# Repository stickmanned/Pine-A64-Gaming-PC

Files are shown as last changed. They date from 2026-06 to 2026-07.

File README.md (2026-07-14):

# Pine A64 Gaming PC

<div align="center">
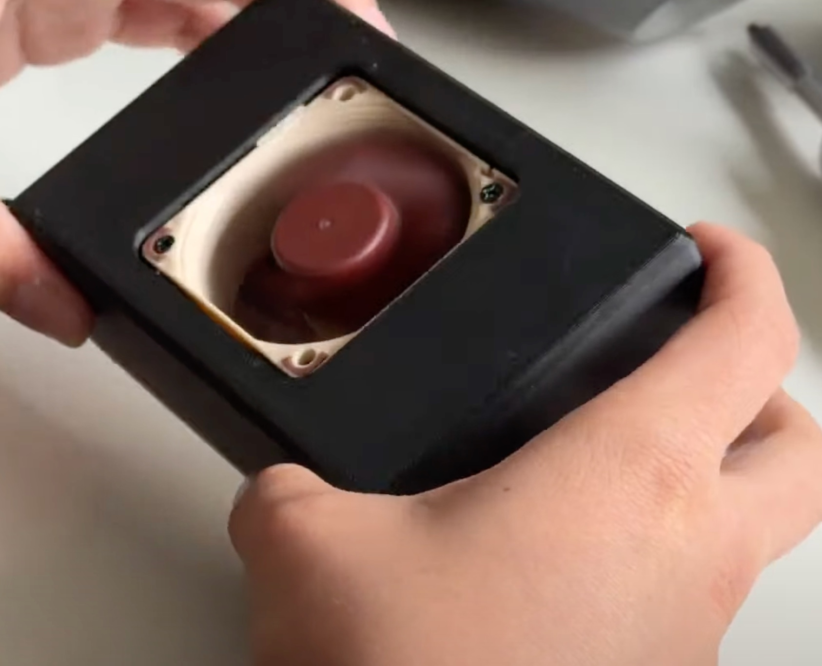
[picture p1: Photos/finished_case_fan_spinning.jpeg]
The final Pine A64 PC build
  
</div>

## Prologue

I got the PINE A64 single-board computer after getting second place at the Equinox hackathon in Vancouver. It originally came in an quite fancy display case made with metal bolts and acrylic. For months, I kept it in its display case on my bookshelf and every time I walked past it, it reminded me that I had a usable computer which I had no plan for.

At the same time, I was using Moonlight to stream games from my main PC because I have a MacBook and I am unable to play some of my favorite games on it; additionally, my room gets too hot during the summer, which with the addition of my PC makes it even hotter. My first idea was to use another normal computer as the receiver, as I have an old Windows laptop lying around, but using a whole computer to stream from another computer felt wasteful and unoriginal. Plus, the laptop's ports were all broken due to a faulty BIOS chip, so I could not connect any peripherals to it. The Pine A64 seemed like a perfect middle ground to my problem: Being small and portable, generating almost no heat due to having a low-powered CPU, and having gigabit ethernet with the addition of a full size HDMI port which I can connect a larger display to.

Back in 2025, around summer, I just set up Moonlight game streaming, which blew me away on how smooth and simple it was. The problem was that I wanted a computer in each of my rooms so I can all connect them to my host PC; therefore, performance would not matter with the added benefits of less heat generation. When I heard about Hack Club Horizons, after winning the PINE A64, I was was finally ready to build it, and I wanted to go to the hackathon, so I submitted it as a Horizons project too with all my hours logged. I came up with the enclosure, created a cooling solution with a spare Noctua fan lying around, power button, software setup, and the rest of the project myself.

## The finished computer

The name "Gaming PC" is a little generous because the Pine A64 is receiving the rendered game from my main PC, not running games locally. I am running DietPi on the microSD card, and along with Moonlight installed, I streamed games over Ethernet. That essentially is all there is on the software side. Physically, I stuck copper heatsinks onto the board, placed a Noctua NF-A6x25 fan above them with the correct voltage control module to output 12V, and then I designed and made a printed case fit around all of it and attached a power button to turn it on and off.

In my final test of the computer, games streamed in 720p with around 20-30 FPS. Fast games such as shooters are not great on it. Slower story games such as driving games are somewhat enjoyable, which surprised me because this is old and slow hardware, and I honestly never expected it to stream games in the first place.

I tried getting hardware video decoding to work and changed a lot of settings, but I kept running into video problems. The finished setup is mainly decoding on the CPU. Its Gigabit Ethernet connection is fine and is definitely not the bottleneck; the video hardware is where it struggles as the CPU is really slow even back in 2016.

Pressing the power button/plugging in the 5V power supply starts the board, and after the first boot checks it goes into Moonlight by itself. I timed about 10 seconds from the press to Moonlight. My button is just a mechanical keyboard switch wired to the Pine A64 power header. It tells the operating system to shut down, rather than yanking the power every time I want the PC to shut down.

The Pine A64 only gets 5V; therefore, I used an MT3608 boost converter to make 12V for the cooling fan, and that 12V output does not draw too much power from the board. The physical power switch was also in the correct orientation during testing. It was not responsible for the crashes that I was experiencing.

[Here is the video of Roblox and BeamNG.drive running on it,](https://photos.app.goo.gl/yZgWkz5E3pNsgPrR7)

<div align="center">
  The fan and Pine A64 before I closed the case
</div>

<div align="center">
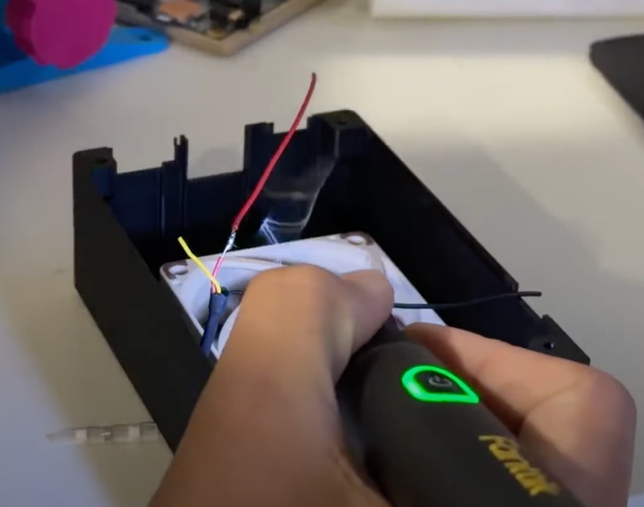
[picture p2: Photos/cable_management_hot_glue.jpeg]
The wiring after I fixed it in place
  
</div>

## Steps to Reproduce

If you want to build this Pine A64 Gaming PC yourself (which I don't recommend since you can get way faster hardware in 2026+, such as a Raspberry Pi), you can follow these steps to manufacture the parts, assemble the hardware, flash the software, and test the final build. 

### 1. Prepare
Before assembling, you would need the following components:

1. **Buy these Components:** 
   Source a Pine A64 board (used ones are like free at this point) a Noctua NF-A6x25 FLX 12V DC fan (get the 5V version if possible), an MT3608 boost converter (if voltages are incompatible), a Cherry MX style mechanical switch (does NOT matter which one you get), copper heatsinks (raspberry pi ones work great), a reliable microSD card (the first microSD failed on me since I got it from shady chinese seller), and wiring hardware.

   <div align="center">
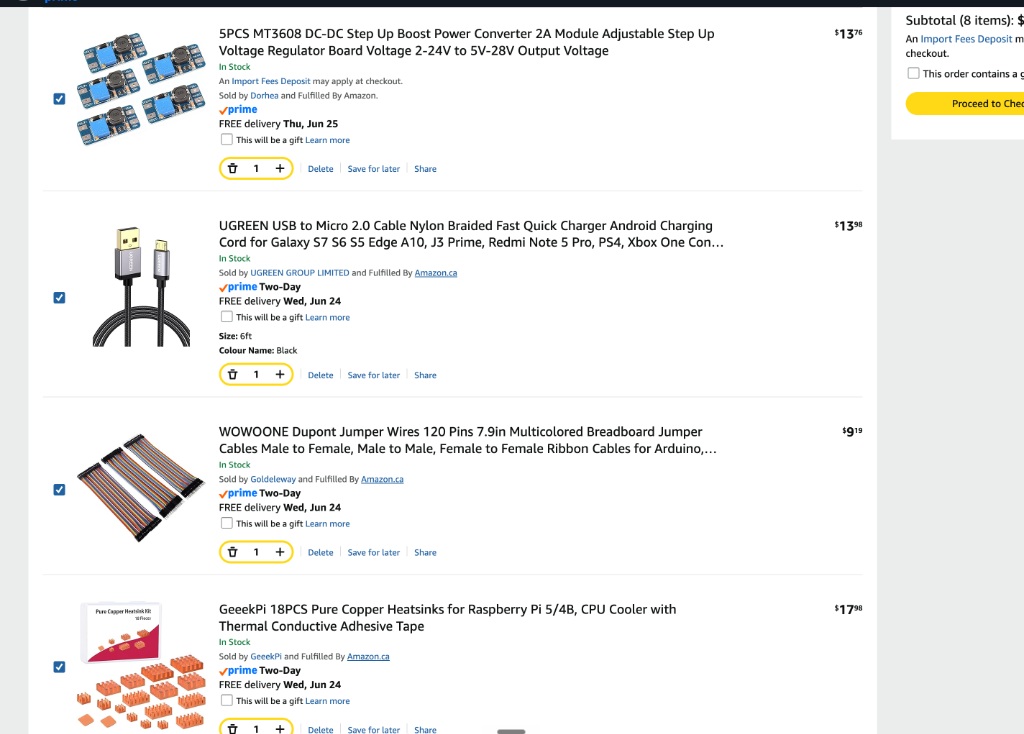
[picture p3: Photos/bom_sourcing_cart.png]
BOM sourcing
     
   </div>

   **You will also need the following**

   - Soldering Iron
   - Multimeter
   - Good quality power brick + microUSB cable
   - 3D printer to print the case and power button
   - Appropriate hardware, such as screws, solder, hot glue gun, etc.
   - Another computer to flash the OS and SSH into the board
   - Monitor
   - Ethernet cable to connect to the network
   - Micro SD card

2. **3D Print the Enclosure:** Use the provided files in the `CAD/` folder.
   * **Top Shell:** Print with 0.20 mm layers and 10% gyroid infill (supports required under the fan cutout). If you have a tool changer 3D printer, I recommend using dedicated support material for easy removal.
   * **Bottom Shell:** Print with 0.16 mm layers and 15% gyroid infill (no supports required).
   
   <div align="center">
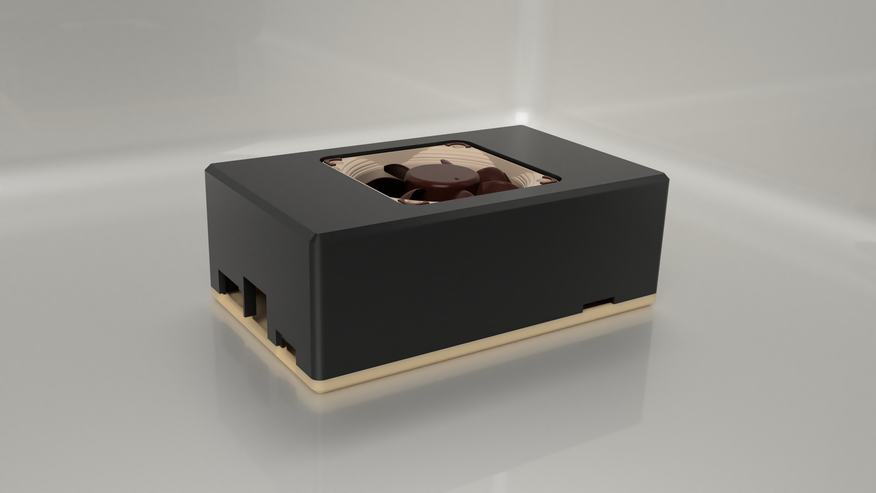
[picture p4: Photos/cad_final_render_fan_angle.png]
CAD render fan angle
     
   </div>

3. **Print the Keycap:** Print the `CAD/power-button-keycap-v3.stl` file for the custom power button keycap, which will fit the case (normal sized keycaps won't fit the cutout).

### 2. Assemble

**Make sure power is disconnected from the Pine A64 before you start assembling**

1. **Install Heatsinks:** Apply the copper heatsinks to the CPU, RAM, and SD card slot before putting anything in the case.
2. **Mount the Fan:** Slide the Noctua fan into the top enclosure and secure it to the internal pillars with M3 screws. Expect to use more force than expected to fit it in. Super gluing the fan onto the pillars is highly recommended since 3D printed inserts might get loose over time.
3. **Wire the Power Switch:** Solder the Cherry MX switch leads to the Pine A64 EXP header (Pin 5 and Pin 6). Snap the switch into the side panel cutout, and after put on the power button keycap.
   
   <div align="center">
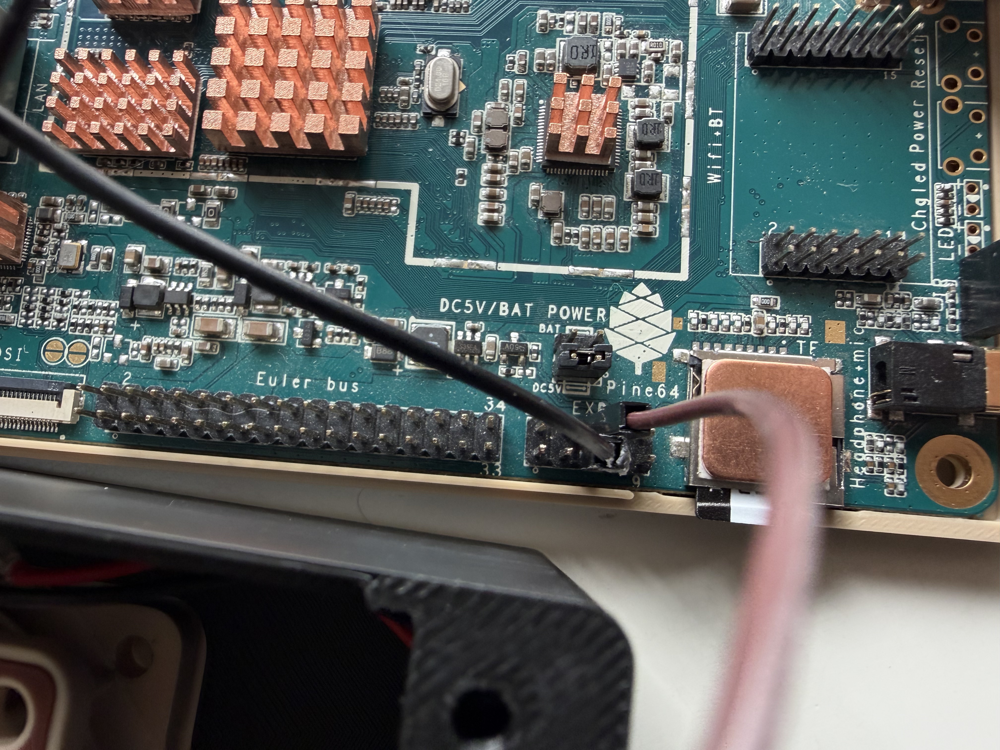
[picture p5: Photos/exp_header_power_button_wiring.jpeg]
EXP header wiring
     
   </div>
   
4. **Wire the Cooling System:** Connect the MT3608 boost converter input to the Pi-2 Bus header 5V (Pin 2) and GND (Pin 6). **IMPORTANT:** Tune the MT3608 output to exactly 12.0V using a multimeter *before* connecting the fan. You can use a flathead screwdriver to rotate the knob until you get an output of 12V. After, connect the fan's red wire to `OUT+` and black to `OUT-`. do not connect the yellow wire. 
   
   <div align="center">
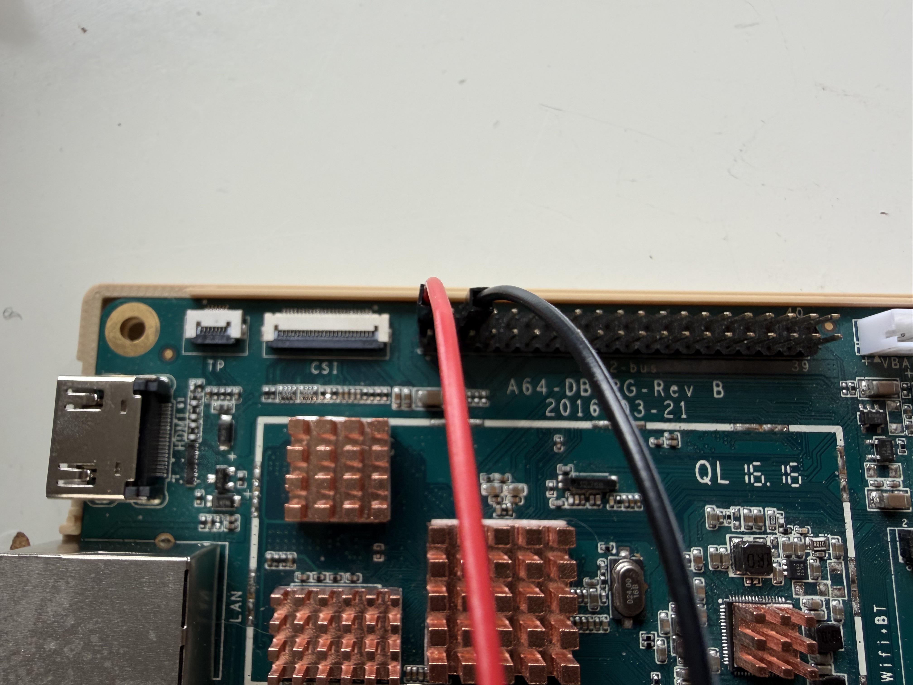
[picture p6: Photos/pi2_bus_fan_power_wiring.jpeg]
Pi-2 Bus fan power wiring
     
   </div>
   
5. **Final Assembly:** Hot glue the wires and MT3608 to the inside of the printed shell, tidy up the cables, and place the board in the bottom shell and screw the top and bottom pieces together using four M3 screws.

### 3. Flash (software configuration)
Here is the tricky part in my opinion:

1. **Flash OS:** Flash DietPi onto a high-quality microSD card. Low-end ones are unreliable and often are the cause of booting issues (speaking from experience). After, insert the microSD card into the Pine A64 and follow the install instructions.
2. **Configure Display:** Edit `/boot/dietpiEnv.txt` to inject a strict resolution limit (e.g., `video=HDMI-A-1:1920x1080@60`). This frees up memory for the hardware video decoder, so you get more frames in Moonlight.
3. **Remove Desktop:** Uninstall the graphical desktop environment completely so the board boots directly to a bare terminal. This saves memory and prevents the X11 overhead.
4. **Setup Moonlight:** Install Moonlight and configure it to run in embedded mode using the KMSDRM video driver.
5. **Configure Autostart:** Add Moonlight to the root user's `.bashrc` profile with a short `sleep 3` delay to avoid race conditions. Write a udev rule to grant open read/write access to the GPU nodes (`/dev/dri/card0` and `/dev/dri/renderD128`).

### 4. Testing

1. **Pre-Power Safety Check:** Ensure 12V from the boost converter only goes to the fan, and never touches the Pine A64 board. 
2. **Power On:** Supply 5V power to the board via micro USB. The board should power on without pressing the power button.
3. **Verify Cooling:** The Noctua fan should spin up and direct air downwards onto the copper heatsinks.
4. **Verify Boot:** Connect the board to an Ethernet network and an HDMI display. It should boot directly into Moonlight in about 10 seconds. A terminal like startup is normal.
5. **Stream:** Pair Moonlight with your host PC and start a game to verify hardware decoding is functioning properly. You should expect low frame rates since the Pine A64 is weak & old, but it should be playable.
   
   <div align="center">
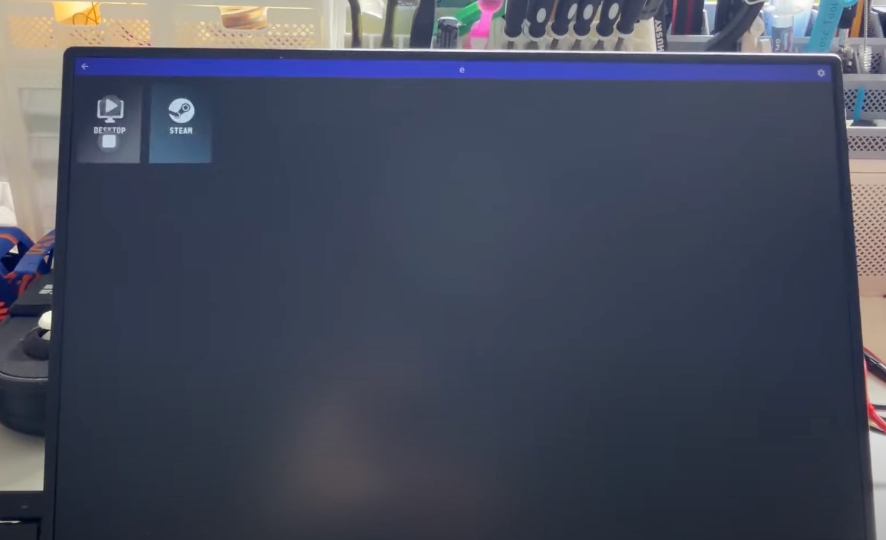
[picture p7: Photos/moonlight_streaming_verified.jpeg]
Moonlight streaming
     
   </div>
   
6. **Test Power Button:** Long press the power button, and you should see the Pine A64 shut down within a few seconds. Short press and it will turn on again.

## Build files and proof
Here are all the relevant build files if you are checking out this project or if you want to replicate it for yourself.

- [24-hour devlog](./Devlog.md) - everything that happened in the 24 hours the project took
- [CAD folder](./CAD) - all the CAD files, such as Fusion and 3D printing files\*
- [wiring PDF](./Hardware/wiring-schematic.pdf) - wiring diagram
- [DietPi and Moonlight configuration](./firmware-config) - OS and software configuration
- [parts and prices](./Pine%20A64%20PC%20Bill%20of%20Materials.csv) - parts and prices
- [recorded build sessions timelapses](https://drive.google.com/drive/folders/1OZEimO6eNiohD2dQr07wJ2Tfkh4ZQb1m?usp=sharing) - recorded build sessions timelapses
- [project spreadsheet](https://docs.google.com/spreadsheets/d/1We2MmTOR3fEgsacE6zURNgYWdwFos29sACSzlIPlyxY/edit?usp=sharing) - project spreadsheet

\* The editable enclosure is `CAD/P64-CASE.f3z`. I included the top and bottom STL files, the 3MF I printed, and the custom power-button keycap. The top shell was printed on a Snapmaker U1 with black Bambu PLA Basic at 0.20 mm layer height and 10% gyroid infill. The bottom came from an Anycubic Kobra X using wood JAYO PLA+ at 0.16 mm and 15% gyroid infill.

There is no custom PCB in this project. The wiring is point to point, so the PDF schematic is the hardware design file instead of a Gerber archive. The firmware folder has the installer and the exact boot, udev, and Moonlight startup files I used. I left the longer setup commands beside those files because that is where I would look for them if I were rebuilding it.

## Epilogue

If I was able to restart this project, I would start with a brand new, more reliable microSD card. I realized mine was dying much too late, after I had already spent hours blaming the operating system.

I would also be more careful with sources. This board is old enough that there is barely any current documentation for some of its problems. I used Google's AI search while debugging and the AI answers hallucinated details about the board, which sent me into more errors. Now I would check those answers against the board documentation and the official wiki before changing system files that I didn't know about.

After finishing this project, I can now install DietPi/linux on a single-board computer, set up a machine without a desktop, work through it using SSH, and make Moonlight start automatically. In 2026, this board is slow, but it is not useless. That was the entire point of the project: proving that old hardware doesn't automatically mean obselete hardware, just like how the corporate overlords want us to think.

## AI use

I used AI as a tool for researching about this board, finding answers to my questions/debugging. I also used some AI to assist me with organizing my ideas/thoughts together for the devlog, but all the writing is my own doing.

I did the CAD work, printing decisions, soldering, wiring, assembly, Linux installation, and physical debugging.

## License

[MIT License](./LICENSE)

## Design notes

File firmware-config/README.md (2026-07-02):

# Pine A64 Gaming PC — Firmware / Config Files

This folder contains the reproducible configuration files used for the Pine A64 gaming PC software setup.

These files are committed to the repository so another person can review, copy, or reinstall the software environment on a freshly flashed DietPi image, instead of retyping commands from the devlog.

## Files

### `boot/dietpiEnv.txt`

DietPi boot environment snippet. Stores the display-related boot setting used during the project: `video=HDMI-A-1:1920x1080@60`. This Hour 6 fix caps HDMI at 1080p before Linux starts, which keeps the Allwinner A64 DRM/KMS display stack from exhausting the CMA memory pool and blocking Moonlight's hardware-accelerated path.

Target location on device:

```bash
/boot/dietpiEnv.txt
```

Do not blindly replace a board's known-good `/boot/dietpiEnv.txt` with a hand-typed file. Back it up first, then merge this repo's `video=HDMI-A-1:1920x1080@60` line into the existing file. The installer does this merge automatically and writes `/boot/dietpiEnv.txt.backup` before changing anything.

### `home/bashrc_moonlight_autostart`

Shell startup logic that automatically launches Moonlight after login on the main TTY, from Hours 8–11. This file is not named `.bashrc` in the repo to avoid overwriting a developer's own local shell config — during installation its contents are appended to the DietPi user's real `.bashrc`.

Target location on device:

```bash
/home/dietpi/.bashrc
```

### `udev/99-kms.rules`

udev rule used to expose KMS/DRM and input device access to the normal DietPi user (Hour 9), required so Moonlight can access the rendering/display and mouse/keyboard devices without running as root.

Target location on device:

```bash
/etc/udev/rules.d/99-kms.rules
```

### `install.sh`

Helper script that backs up existing config on the board, merges the tracked HDMI cap into `/boot/dietpiEnv.txt`, installs the udev rule, and appends the Moonlight autostart block. Run from inside `firmware-config`:

```bash
chmod +x install.sh
sudo ./install.sh
```

After installation, edit `/home/dietpi/.bashrc` to replace `<HOSTNAME_OR_IP>` with your gaming PC's actual hostname or LAN IP, then reboot:

```bash
sudo reboot
```

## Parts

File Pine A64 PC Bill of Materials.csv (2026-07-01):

Component Name | Part Number / Specs | Category | Quantity | Unit Price CAD | Total Cost CAD | Source Link | Status | Notes
Pine A64 single-board computer | Pine A64 2GB Rev B / Allwinner A64 | SBC | 1 | $45.00 | $45.00 | https://wiki.pine64.org/wiki/PINE_A64 | Owned | Main compute board; approximate replacement value because this board was already owned
Noctua NF-A6x25 FLX 60mm fan | NF-A6x25 FLX / 12V / 0.96W | Cooling System | 1 | $24.95 | $24.95 | https://noctua.at/en/nf-a6x25-flx | Owned | 12V active cooling fan; exact model matters for size, voltage, and mounting hole spacing
WOWOONE Dupont jumper wires | 120pcs male/female jumper wire kit | Electronics/Pins | 1 | $9.19 | $9.19 | https://www.amazon.ca/gp/product/B07RN4WN2N?smid=A23IH7XHL03K4&psc=1 | Ordered | Used for header wiring and prototyping
MT3608 DC-DC step-up boost converter | 5PCS MT3608 adjustable boost module | Power | 1 | $13.76 | $13.76 | https://www.amazon.ca/gp/product/B0C8D658R7?smid=A3CX4TQNUXMB0L&psc=1 | Ordered | Steps 5V input rail up to 12.0V for the fan only
UGREEN Micro USB cable | Micro USB power/data cable | Power Delivery | 1 | $13.98 | $13.98 | https://www.amazon.ca/gp/product/B01NBHYAR0?smid=AKXVBT49GGF3B&th=1 | Ordered | Used for power/USB routing during the final build
GeeekPi pure copper heatsinks | 18pcs copper heatsink kit | Cooling | 1 | $17.98 | $17.98 | https://www.amazon.ca/gp/product/B0CJDSGBL8?smid=AOP0CH6UTUPHT&psc=1 | Ordered | Passive heatsinks for SoC and power components
M3 brass threaded insert kit | M3 heat-set insert assortment | 3D Printing Hardware | 1 | $26.79 | $26.79 | https://www.amazon.ca/gp/product/B0CNRSJ1B2?smid=A1BORF6OB9GGNC&psc=1 | Ordered | Standard M3 inserts for printed enclosure mounting points
3D printer filament | PLA or PETG / approx 0.2kg consumed | 3D Printing Hardware | 0.2 | $25.00 | $5.00 | Local 1kg spool | Owned | Approximate material consumed from an owned spool; any stiff PLA/PETG-like filament should work
M3 button-head screw assortment | M3 metric button-head screws | 3D Printing Hardware | 1 | $12.00 | $12.00 | Local hardware assortment | Owned | Approximate replacement value; used for fan/enclosure fastening
Momentary push button / Cherry MX-compatible switch | Momentary normally-open keyboard switch | Electronics/Pins | 1 | $1.50 | $1.50 | Owned switch assortment | Owned | External power button wired across EXP pin 5 and EXP pin 6
5V 3A USB wall power adapter | Regulated 5V / 3A USB PSU | Power Delivery | 1 | $12.00 | $12.00 | Owned power adapter | Owned | Main low-voltage supply for the Pine A64 and MT3608 input

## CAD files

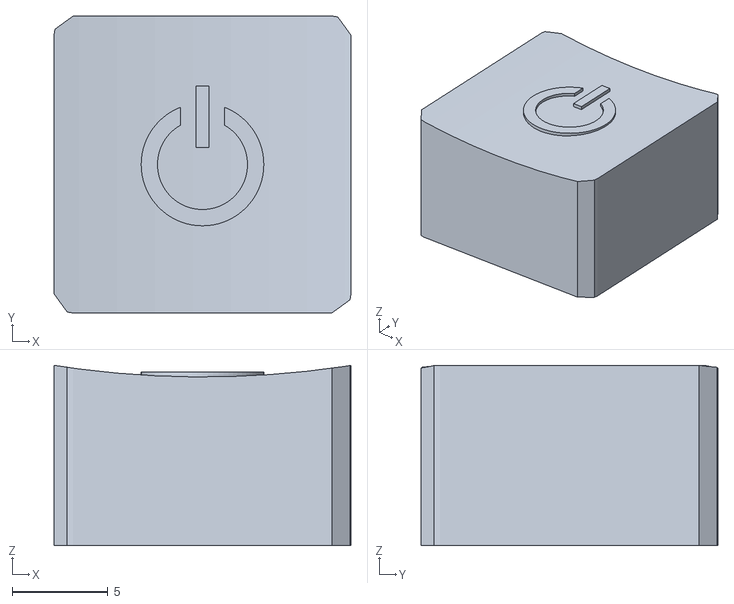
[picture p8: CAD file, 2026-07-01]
CAD/power-button-keycap-v3.stl
15.5 x 15.5 x 9.40

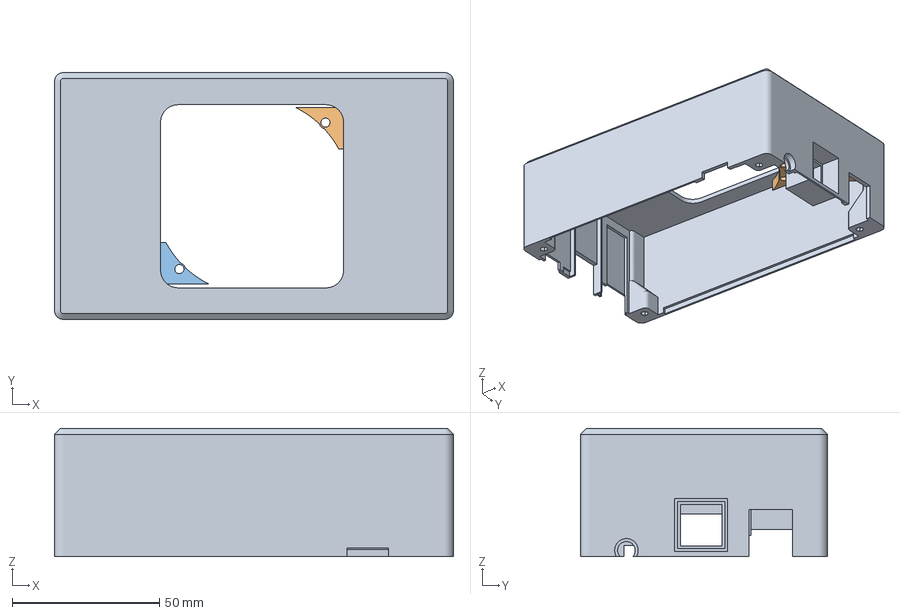
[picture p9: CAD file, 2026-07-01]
CAD/P64-case-top-v1.4.1.3mf
135.5 x 83.8 x 43.5 mm
20221023_PINE-A64_case_top (1)

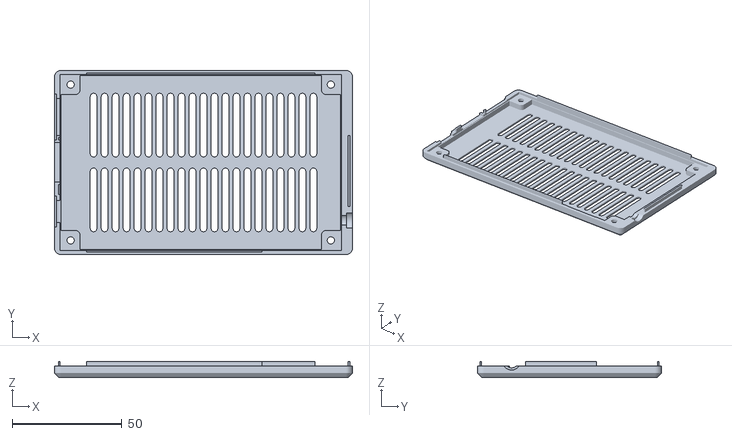
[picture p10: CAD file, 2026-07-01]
CAD/P64-case-bottom.stl
135.5 x 83.8 x 7.30

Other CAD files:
CAD/P64-case-top-v1.4.1.stl

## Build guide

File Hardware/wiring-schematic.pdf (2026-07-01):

# Pine A64 Gaming PC - Wiring Schematic

Exported reviewer schematic matching README.md. No custom PCB; point-to-point low-voltage wiring only.

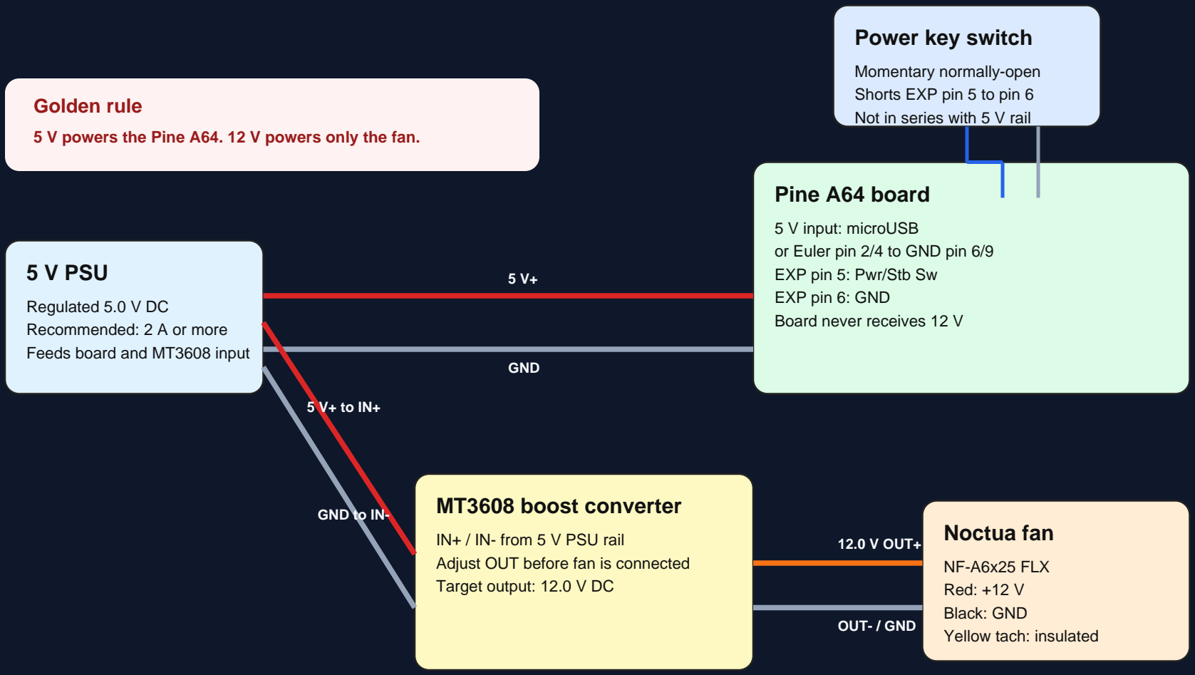
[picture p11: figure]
5 V PSU; Regulated 5.0 V DC Recommended: 2 A or more Feeds board and MT3608 input; Pine A64 board; 5 V input: microUSB or Euler pin 2/4 to GND pin 6/9 EXP pin 5: Pwr/Stb Sw EXP pin 6: GND Board never receives 12 V; MT3608 boost converter; IN+ / IN- from 5 V PSU rail Adjust OUT before fan is connected Target output: 12.0 V DC; Noctua fan; NF-A6x25 FLX Red: +12 V Black: GND Yellow tach: insulated; Power key switch; Momentary normally-open Shorts EXP pin 5 to pin 6 Not in series with 5 V rail; GND; GND to IN-; 12.0 V OUT+; OUT- / GND; Golden rule

### Pre-power checklist

1. Verify PSU is about 5.0 V DC.
2. Verify MT3608 input polarity before power.
3. Adjust MT3608 OUT+/OUT- to 12.0 V before connecting the fan.
4. Connect fan red to OUT+, black to OUT-, and insulate the yellow tach wire.
5. Verify the key switch only shorts EXP pin 5 to EXP pin 6 when pressed.
6. Confirm no 12 V conductor can touch any Pine A64 header or board input.

5 V powers the Pine A64. 12 V powers only the fan.

Source: README.md wiring section and Devlog Hour 23

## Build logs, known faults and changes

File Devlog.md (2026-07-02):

# Engineering Devlog: Pine A64 Gaming PC

Welcome to the engineering devlog for the Pine A64 Gaming PC project. This document serves as the repository for progress logs, design choices, component testing, and build records as we transform the Pine A64 single-board computer into a custom-cooled, custom-enclosed gaming PC.

Here is the spreadsheet which organizes the entire project: https://docs.google.com/spreadsheets/d/1We2MmTOR3fEgsacE6zURNgYWdwFos29sACSzlIPlyxY/edit?usp=sharing

Build session timelapses are archived here for Horizons review: https://drive.google.com/drive/folders/1OZEimO6eNiohD2dQr07wJ2Tfkh4ZQb1m?usp=sharing

## Hour 1: Project Teardown & Component Sourcing

* **Date:** June 22, 2026

### Activity Summary
Removed the pre-existing stock acrylic enclosure from the Pine A64 to expose the bare board. Finalized the engineered Bill of Materials (BOM) for the 12V active cooling system and ordered the MT3608 boost converter, copper heatsinks, and wiring hardware.

### Engineering Notes
> [!NOTE]
> The original acrylic mounting hardware was kept and carefully stored. The thread pitches will be cross-referenced with planned M3 heat-set inserts to ensure compatibility during the custom enclosure design.

### Media & Sourcing Logs

#### 1. Bare-Board Teardown
Exposed Pine A64 board (Rev B, 2016-03-21) ready for thermal measurements and custom mount planning:
<div align="center">
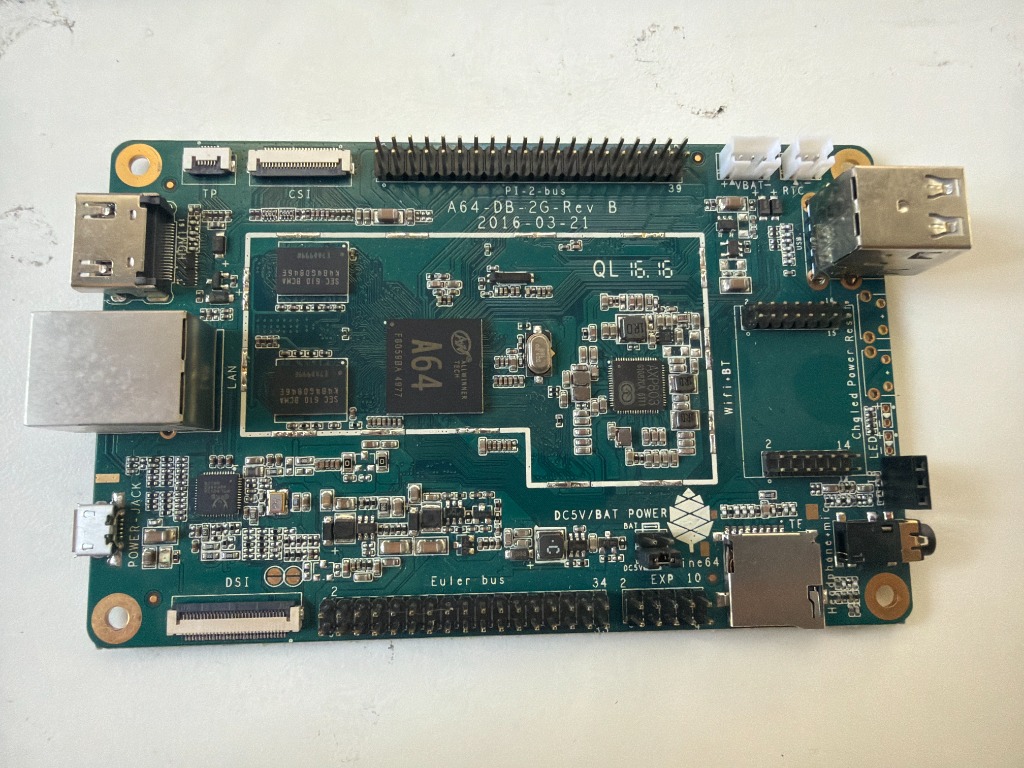
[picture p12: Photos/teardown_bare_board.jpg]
Pine A64 Bare Board Teardown
  
</div>

#### 2. Active Cooling Fan
A Noctua NF-A6x25 FLX 12V DC (0.96W, 0.08A) fan will be integrated to provide high-static-pressure, low-noise active cooling:
<div align="center">
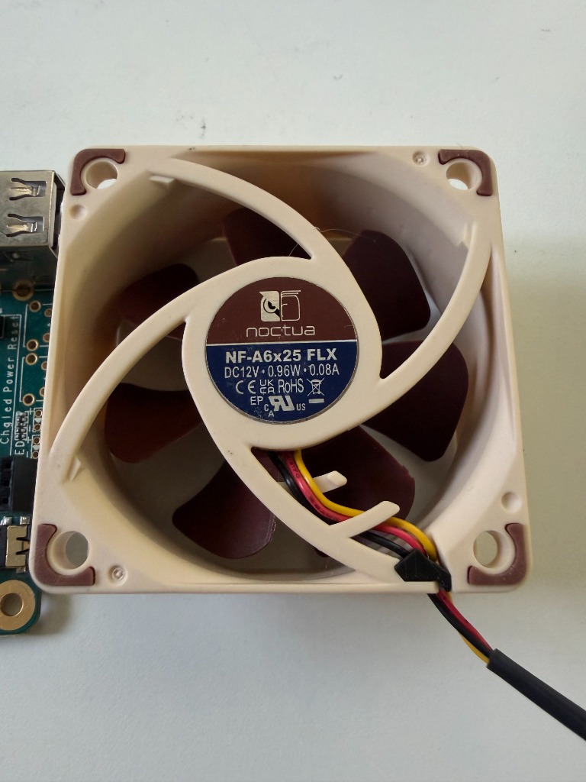
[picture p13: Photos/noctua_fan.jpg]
Noctua 12V Fan
  
</div>

#### 3. Sourced Bill of Materials (BOM)
Order placed for essential power management, thermal, and prototyping hardware:
<div align="center">
  Amazon Sourcing Shopping Cart
</div>

## Hour 2: Documentation Review & Pinout Architecture Analysis

* **Date:** June 22, 2026

### Activity Summary
Researched the Pine A64 hardware by watching unboxing tutorials and reviewing the official PINE64 documentation. Mapped out the exact pins needed for the custom cooling fan and the external power button.

### Engineering Notes
* **Pi-2 Bus (40-pin header):** Found the power pins for the cooling system. Pins 2 and 4 provide 5V power, and Pin 6 is Ground (GND). These will connect to the MT3608 boost converter.
* **EXP Header:** Found the hardware power switch pins. Pin 5 (`Pwr/Stb Sw`) and Pin 6 (`GND`) will connect to the external momentary tactile button.

### Reference Links
* [PINE_A64 Wiki](https://wiki.pine64.org/wiki/PINE_A64)
* [Pine A64 Schematic & Pin Assignment PDF](https://files.pine64.org/doc/Pine%20A64%20Schematic/Pine%20A64%20Pin%20Assignment%20160119.pdf)
* [PINE64 official Schematics & Certifications Documentation](https://pine64.org/documentation/Pine_A64/Further_information/Schematics_and_certifications/)
* [Pine A64 Tutorial/Unboxing Reference 1](https://www.youtube.com/watch?v=4FUbQ5n3BIg)
* [Pine A64 Tutorial/Unboxing Reference 2](https://www.youtube.com/watch?v=FxGeloh80RQ)

## Hour 3: OS Selection, Flashing, & Initial Boot Diagnostics

* **Date:** June 24, 2026

### Activity Summary
Selected DietPi as the core operating system to minimize background processing and maximize network stability for PC game streaming (Moonlight). Flashed the OS image using BalenaEtcher. Initiated the first boot sequence but encountered immediate HDMI display failures and random system halts.

### Engineering Notes
* **Initial Boot Failures (Black Screen):** Diagnosed as potential voltage sags (brownouts) caused by peripheral power spikes.
* **USB Hotplug Brownouts:** Investigated by cold-plugging a keyboard before applying power to bypass capacitor draw spikes.
* **HDMI Handshake Failure:** Realized the HDMI handshake was failing due to resolution mismatches, requiring a pivot to a headless (SSH) configuration approach.

## Hour 4: Network Diagnostics, Subnet Sweeping, & Hardware Isolation

* **Date:** June 24, 2026

### Activity Summary
Attempted to establish a headless SSH connection to bypass the broken HDMI output. Upgraded the power delivery system to an Anker GaNPrime 100W brick to rule out amperage deficits. Performed advanced subnet sweeping to track down the board's IP address. Concluded with a bare-board isolation test.

### Engineering Notes
* **Network Topology Issue:** Discovered the local OpenWrt router overrides the default `.local` mDNS protocol in favor of `.lan`. Wrote a custom bash loop to brute-force map the subnet:
  ```text
  for ip in {1..254}; do ping -c 1 -W 50 192.168.1.$ip &> /dev/null & done; sleep 2; arp -a
  ```
* **MAC Address Analysis:** Successfully identified the board's dynamic IP (`192.168.1.250`) by analyzing the locally administered MAC address (`2:ba:3e:cd:49:25`) generated by DietPi.
* **Isolation Test & Power Delivery:** Despite the Anker 100W GaN upgrade, continuous pings showed 100% packet loss, indicating a recurring physical crash. Conducted a "Bare Board Isolation Test" (power only, no SD card). This proved that either the Micro-USB cable's electrical resistance is too high, or the MicroSD card itself is spiking power draw / physically corrupted, preventing the bootloader from executing.

## Hour 5: The Performance Bottleneck & Root Cause Analysis

* **Date:** June 26, 2026

### Activity Summary
Initially, the Moonlight stream was completely unplayable, hovering around 2 frames per second.

* **The Problem:** The stream was relying on "software decoding." This means the Pine A64's general CPU was trying to mathematically calculate every pixel of the video stream. For a 60 FPS stream, the CPU simply couldn't keep up.
* **The Root Cause:** In a previous session, to prevent my 1440p monitor from crashing the system, the OS was forced onto a basic display driver called `fbdev` (framebuffer). While this made the desktop stable, `fbdev` is essentially a "dumb" canvas. It physically blocked Moonlight from accessing the Pine A64's built-in Hardware Video Decoder (the CedarX VPU), forcing the system to fall back on the CPU.

## Hour 6: Unlocking Hardware Acceleration via Kernel Modification

* **Date:** June 26, 2026

### Activity Summary
To get 60 FPS, I needed to re-enable the modern DRM (Direct Rendering Manager) display driver so the hardware decoder could function. However, I had to prevent the 1440p monitor from crashing the system's limited memory pool (CMA).

* **The Solution:** Instead of fixing this in the operating system, I went a level deeper into the Linux kernel bootloader. I modified `/boot/dietpiEnv.txt` to inject a strict resolution limit: `video=HDMI-A-1:1920x1080@60`.
* **Details:** By forcing the display to negotiate at 1080p before the OS even loaded, the display driver required significantly less memory. This left enough room in the shared memory pool for the hardware video decoder to turn on. I then deleted the legacy `fbdev` configuration, allowing the hardware-accelerated pipeline to take over.

## Hour 7: The Embedded Transition (Killing the Desktop)

* **Date:** June 26, 2026

### Activity Summary
Even with hardware decoding enabled, running a full graphical desktop environment (XFCE) in the background consumes valuable memory and adds input latency. To make this a true "appliance," I decided to run Moonlight on the bare metal, without a desktop.

* **The Challenge:** DietPi (the operating system) actively fought this change. Even after using system commands to disable the display manager (`systemctl mask lightdm`), the OS would still boot into a graphical desktop.
* **Investigation:** After digging into the OS architecture, I discovered DietPi uses hidden startup scripts (`/boot/dietpi/dietpi-login`) that forcefully launch the X11 server on boot.
* **The Solution:** I took the nuclear option. I completely uninstalled the XFCE desktop environment and all graphical components (`apt purge xfce4*`). If the desktop physically didn't exist on the drive, the background scripts couldn't launch it.

## Hour 8: Rebuilding the Graphics Pipeline (EGLFS & KMS)

* **Date:** June 26, 2026

### Activity Summary
With the desktop gone, the system successfully booted to a raw text terminal. However, launching Moonlight now caused two new issues:
1. There was no mouse cursor.
2. The stream crashed immediately upon launching, throwing SDL2 display errors.

* **The Cause:** Moonlight usually relies on the desktop environment to draw the cursor and manage video windows. Without a desktop, it didn't know how to talk to the screen.
* **The Solution:** I configured Moonlight to operate in an embedded mode using EGLFS (Embedded Graphics Library Framebuffer System). I injected specific environment variables into the root user's `.bashrc` profile:
  * `QT_QPA_PLATFORM=eglfs`: Tells the UI to draw directly to the screen without needing a window manager.
  * `SDL_VIDEODRIVER=kmsdrm`: Tells the video stream to route directly to the Kernel Mode Setting hardware layer.
  * `QT_QPA_EGLFS_HIDECURSOR=0`: Forces the software to draw a mouse cursor manually.

## Hour 9: Overcoming Hardware Initialization Races

* **Date:** June 26, 2026

### Activity Summary
The final hurdle occurred during the automated boot process. When the system booted, it threw a wall of text errors: `Failed to load EGL device integration "kms"` and `Failed to initialize KMS`.

* **The Cause (Race Condition & Permissions):** Because the system was booting so fast, the custom script was trying to launch Moonlight before the Linux kernel had finished waking up the GPU and HDMI ports. Furthermore, the terminal user didn't have the correct security permissions to access the bare-metal graphics hardware.
* **The Final Fixes:**
  * **Timing Delay:** I added a simple `sleep 3` command to the boot script. This gave the hardware drivers exactly 3 seconds to fully initialize before Moonlight asked for access.
  * **Hardware Permissions:** I wrote a custom udev rule (`99-kms.rules`) that permanently grants open read/write access (`MODE="0666"`) to the GPU nodes (`/dev/dri/card0` and `/dev/dri/renderD128`).
  * **Cleanup:** I moved the broken DietPi login scripts to backup files to clear terminal errors and fixed minor syntax formatting in the bash profile.

## Hour 10: Input/Output Diagnostic Sweep & System Boot Order Analysis

* **Date:** June 26, 2026

### Initial State Observed
* **Boot Environment:** Device boots into a minimal terminal (DietPi CLI environment) with Moonlight configured to launch automatically.
* **Input Issues:** Mouse input is not functional or behaves inconsistently.
* **Boot Errors:** Early boot errors referencing missing login scripts: `/boot/dietpi/dietpi-login: No such file or directory`.

### Diagnostics Performed
* **Input Subsystem Inspection:** Verified `/proc/bus/input/devices` and confirmed multiple valid HID devices (including the wireless keyboard/mouse receiver). Event nodes were correctly created (`/dev/input/event*`), and the mouse device was detected and producing events via `evtest`.
  * *Conclusion:* Hardware input is fully functional at the kernel level.
* **System Service State Review:** Running `systemctl list-unit-files` showed multiple masked services, and mixed enabled/disabled network and display services, but no dedicated Moonlight systemd service.
  * *Conclusion:* The startup flow is currently shell-based rather than service-based.
* **GPU / Display Stack Inspection:** Confirmed `sun4i-drm` display engine is initialized and DRM is active. The GPU driver is loaded (`lima 1.1.0`) with a framebuffer active at the HDMI output.
  * *Conclusion:* The display stack is functional, but constrained by the low-end GPU.
* **Boot Script Investigation:** Examined `/boot/boot.cmd` (standard U-Boot chain is intact, no Moonlight integration at firmware level) and reviewed `/boot/dietpiEnv.txt` (minimal overlays, no GPU tuning applied).
  * *Conclusion:* No early boot acceleration or optimization layers are present.

### Key Issue Identified
Moonlight was being launched too early in the shell environment. Input devices and the DRM stack were not fully initialized at execution time, and the EGLFS rendering path was causing instability.

## Hour 11: Startup Logic Optimization & Render Backend Performance Tuning

* **Date:** June 26, 2026

### Goal
Stabilize Moonlight startup and improve rendering performance.

### Major Interventions
1. **Bash Startup Cleanup:** Investigated `/root/.bashrc` and found the Moonlight auto-exec logic embedded with a waiting loop on `/dev/input/event9` followed by `exec moonlight-qt`.
   * *Problem:* A race condition exists on input device readiness, with no guarantee the DRM or GPU stack is initialized.
2. **Environment Variable Adjustments:** Tested multiple variables including:
   * Qt EGLFS mode: `QT_QPA_PLATFORM=eglfs` (caused cursor issues and rendering warnings)
   * SDL KMS mode: `SDL_VIDEODRIVER=kmsdrm` (proved more stable on this hardware)
   * Hardware decode flag: `MOONLIGHT_USE_HW_DECODER=1`
3. **Runtime Directory Fixes:** Detected that `XDG_RUNTIME_DIR` was invalid or not set. Created `/run/user/0` with correct permissions as a temporary fix, which reduced Qt runtime warnings and improved session consistency.
4. **Input Behavior Analysis:** Mouse input was confirmed functional via kernel event testing; the problem was isolated to rendering backend mismatch (EGLFS cursor handling limitations).
5. **Performance Diagnosis:** Identified a critical bottleneck: the Pine A64 GPU is a Mali-400 (`lima` driver) which lacks a strong hardware decode path for streaming. This results in CPU-bound H.264 decoding, causing severe frame drops (~2 FPS behavior observed) and cursor lag amplified by rendering stalls.
6. **Architectural Correction Proposed:** Transitioning from bash-based autostart and EGLFS control to a systemd-managed startup using the SDL/KMS rendering path and delayed initialization.

## Final State & Outcome Summary (After 11 Hours)

### System Status
* **Working:**
  * Moonlight launches automatically.
  * DRM display is functional.
  * Input devices are detected.
  * GPU driver is active.
* **Partially Broken / Unstable:**
  * EGLFS rendering instability.
  * Cursor artifacts and warnings.
  * Poor frame pacing.
  * High input latency.

### Root Causes Identified
1. Wrong rendering backend for hardware (EGLFS overloading the system).
2. CPU-bound video decode pipeline (Mali-400 driver constraints).
3. Shell-based startup causing race conditions.
4. Lack of systemd-controlled initialization order.

### Outcome Summary
This session successfully transitioned the system from a **"working but unstable shell-launched streaming prototype"** to a **"functionally correct but architecturally misaligned bare-metal streaming stack."**

## Hour 12: CAD Case Design & Reference Import

### Activity Summary
Began the Computer-Aided Design (CAD) phase for the custom PC case using Fusion 360. 

### Engineering Notes
* **Reference Geometry:** Researched existing case designs for the PINE A64. Found a relevant model on Printables ([model 301005](https://www.printables.com/model/301005-pine-a64-case)) and imported it into Fusion to analyze its dimensions and mounting strategy.
* **Component Integration:** Imported step files for the Noctua NF-A6x25 fan and the Cherry MX mechanical switch (for the power button) into the Fusion assembly to ensure accurate clearances and layout planning.

## Hour 13: Fan Mounting Integration

### Activity Summary
Designed the top section of the enclosure specifically focusing on the integration of the Noctua active cooling fan.

### Engineering Notes
* **Mounting Pillars:** Added four structural pillars with M3 screw holes to the internal chassis design. These are precisely spaced to align with the Noctua fan's mounting holes, ensuring a secure and vibration-free fit.

<div align="center">
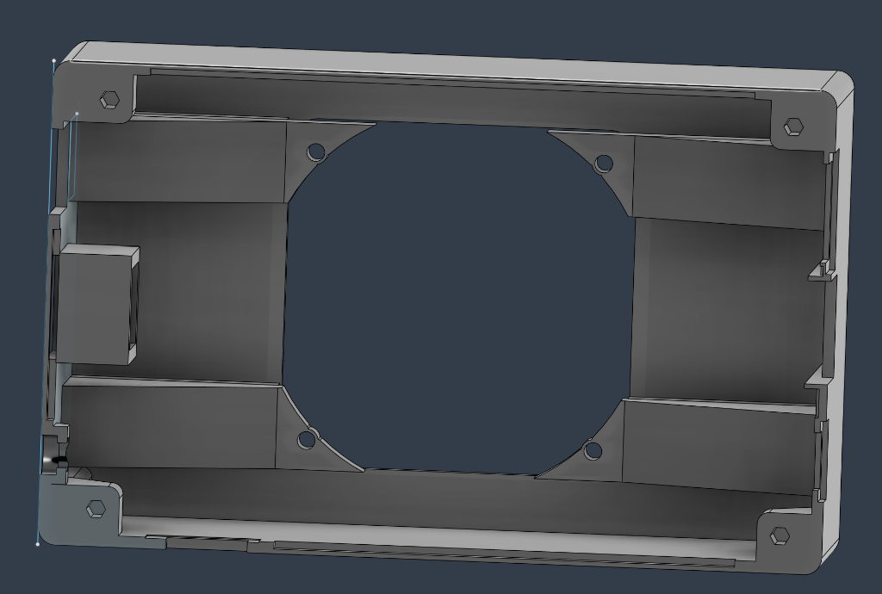
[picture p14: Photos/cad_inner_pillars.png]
Inner view of CAD chassis showing 4 mounting pillars
  
</div>

## Hour 14: Power Button Cutout Design

### Activity Summary
Engineered the mounting mechanism for the external Cherry MX power switch on the side panel of the case.

### Engineering Notes
* **Snap-Fit Mechanism:** Creating the cutout was mechanically tricky. It required extruding three distinct square profiles so the switch would snap perfectly into place. 
* **Tolerances:** Designed the bottom layer of the cutout to be precisely 1.5mm thick, providing the ideal flexibility and clearance for an easy, secure snap-fit installation.

<div align="center">
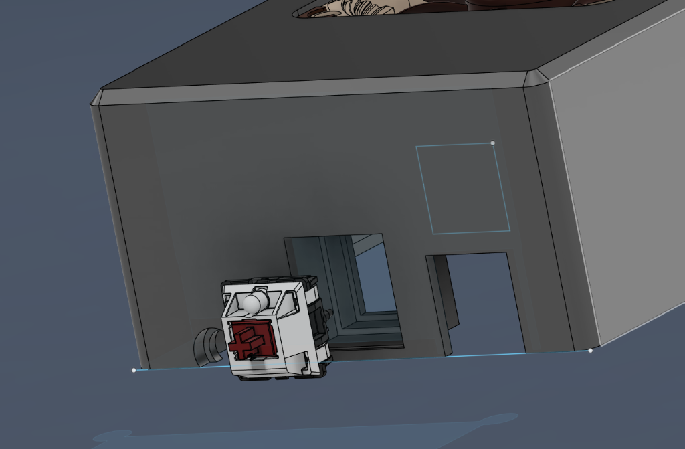
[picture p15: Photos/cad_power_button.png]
CAD view of side panel with Cherry MX power switch cutout
  
</div>

## Hour 15: Top Enclosure & Fan Cutout

### Activity Summary
Finalized the topmost section (the roof) of the case enclosure to enclose the components while providing necessary airflow.

### Engineering Notes
* **Enclosure Height:** Extruded the side walls 4mm upwards so they sit flush with the height of the installed Noctua fan.
* **Airflow Optimization:** Added the full top cover and created a precise fan cutout so only the fan blades and hub are exposed. Applied a chamfer to the cutout edges for a cleaner aesthetic and to potentially reduce air turbulence.

<div align="center">
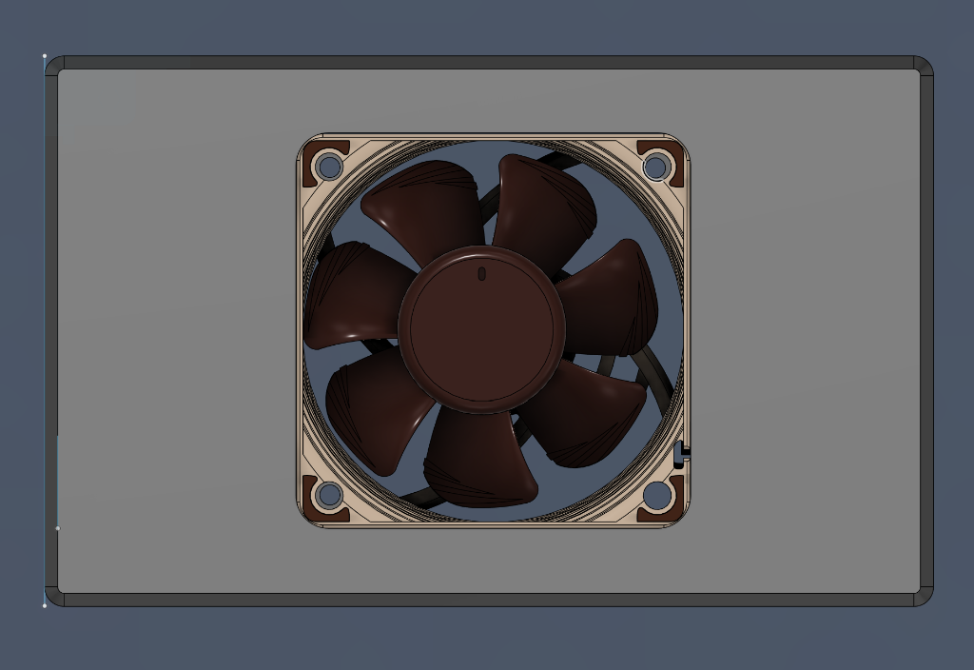
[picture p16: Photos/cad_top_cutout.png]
Top view of the enclosure and chamfered fan cutout
  
</div>

## Hour 16: 3D Printing Optimization & Revision

### Activity Summary
Optimized the Fusion 360 design for 3D printing, ran a test print, and performed a mechanical revision based on physical fitment testing.

### Engineering Notes
* **Print Optimization:** Spent the first part of the session eliminating structural gaps by adding solid extrusions to make the design more manifold and printer-friendly.
* **Mechanical Revision:** After printing the prototype, discovered a clearance issue: the fan could not physically slide into place because all four mounting pillars blocked its path. 
* **The Fix:** Removed one of the four mounting pillars in the CAD model. This modification provides enough clearance for the fan to slide in perfectly while still retaining sufficient structural support from the remaining three pillars.

<div align="center">
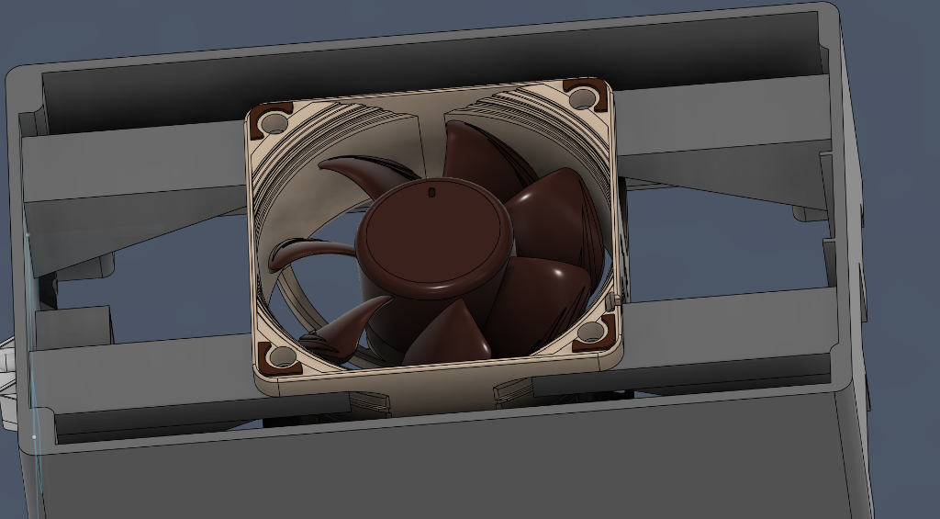
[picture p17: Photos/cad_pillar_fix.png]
Inside view showing fan mounted on pillars with 1 pillar removed for clearance
  
</div>

## Hour 17: Final Wiring Hardware & Pi-2 Bus Power Tap

* **Date:** June 30, 2026

### Activity Summary
Sourced and staged the final wiring hardware needed to permanently connect the Noctua fan and power button into the printed enclosure, then soldered the fan's power leads directly onto the Pi-2 bus 40-pin header identified back in Hour 2.

### Engineering Notes
* **Hardware Staged:** MT3608 boost converter modules, a UGREEN USB extension cable (routed out through the rear panel for SSH/power access without opening the case), and a 40-pin Dupont jumper wire set for breaking out the EXP header power-button pins.
* **Fan Power Tap:** Soldered the fan's red (+) lead to Pin 2 (5V) and the black (–) lead to Pin 6 (GND) on the Pi-2 bus header, matching the pinout mapped in Hour 2. Leads run from the header directly into the MT3608 input side before stepping up to the fan.

<div align="center">
  Staged final wiring hardware: MT3608 boost converter, UGREEN USB extension cable, and 40-pin Dupont jumper set
</div>

<div align="center">
  Fan power leads soldered onto the Pi-2 bus 40-pin header, Pin 2 (5V) and Pin 6 (GND)
</div>

## Hour 18: Power Button Assembly & EXP Header Wiring

* **Date:** June 30, 2026

### Activity Summary
Built out the external power button as its own sub-assembly before wiring it into the board, then connected it to the EXP header pins mapped during the Hour 2 pinout analysis.

### Engineering Notes
* **Switch Prep:** Mounted the Cherry MX switch in a printed jig and soldered its two leads (yellow signal, red-brown ground) directly to the switch terminals, keeping the joints small enough to still snap into the Hour 14 side-panel cutout.
* **Board Connection:** Routed those same leads to the EXP header, adjacent to the board's `DC5V/BAT POWER` silkscreen: Pin 5 (`Pwr/Stb Sw`) and Pin 6 (`GND`). A short pigtail runs from the header, alongside the audio jack, out to the switch in the side panel.
* **Strain Relief:** Hot glue was applied over the header connection to prevent the fine-gauge leads from working loose during case assembly/disassembly.

<div align="center">
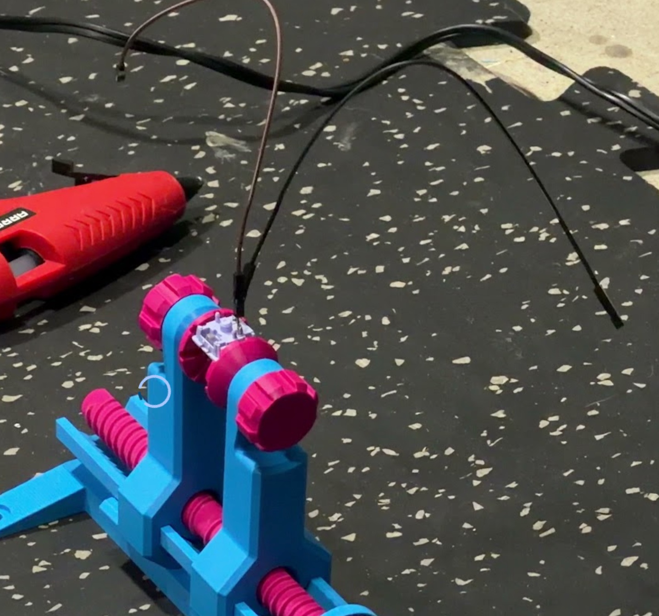
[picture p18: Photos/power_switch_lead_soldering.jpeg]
Cherry MX power switch held in a printed jig while leads are soldered to its terminals
  
</div>

<div align="center">
  Close-up of power button leads soldered to the EXP header Pwr/Stb Sw and GND pins, with hot glue strain relief
</div>

## Hour 19: Final Case Assembly

* **Date:** June 30, 2026

### Activity Summary
Installed the fan into the printed top enclosure on its three mounting pillars and seated the Pine A64 board into the bottom shell, bringing every subsystem wired in Hours 17–18 into one physical unit for the first time.

### Engineering Notes
* **Fan Seated:** Confirmed the fan sits flush on the three remaining pillars (per the Hour 16 clearance fix) with the airflow arrow oriented onto the board's heatsinks.
* **Fit Check:** Verified all wiring (fan power, power button, USB extension) had enough slack to route cleanly without pinching once the case was closed. Cable routing itself was left for Hour 20.

<div align="center">
  Fan mounted inside the printed top enclosure next to the Pine A64 board, ready for final close-up
</div>

## Hour 20: Cable Management & Final System Test

* **Date:** June 30, 2026

### Activity Summary
Cleaned up the internal wiring before closing the case for good, then ran the full system test on the completed build.

### Engineering Notes
* **Cable Management:** Hot-glued the fan leads and the MT3608 boost converter directly to the inside of the printed shell. This keeps both from shifting or rattling around loose next to the board, and routes the wiring flush against the wall instead of draped across the heatsinks, resulting in a cleaner build and one less thing to catch when the case is opened for maintenance.
* **Full System Test:** Powered on the fully closed unit. The power button reliably starts and shuts down the board on each press, the fan spins up immediately and moves air across all heatsinks, and DietPi boots straight to the Moonlight auto-launch script from Hour 11.
* **Moonlight Verified:** Paired with the host gaming PC and streamed a live session end-to-end through the fully enclosed case, confirming the DRM/KMS pipeline, hardware decode path, and cooling solution all work together under real streaming load, not just on the bare board.

<div align="center">
  Hot-gluing the fan wiring inside the printed enclosure for strain relief and clean cable routing
</div>

<div align="center">
  Closed, finished enclosure with the fan visibly spinning through the top cutout
</div>

<div align="center">
  Moonlight streaming session running on the connected display, confirming end-to-end functionality
</div>

## Hour 21: Design Source Files & Repository Cleanup

* **Date:** June 30, 2026

### Activity Summary
Prepared for final submission to the [Hack Club Horizons hardware shipping guide](https://guides.horizons.hackclub.com/guides/shipping-guide/#-hardware), exported and committed the CAD design source files so the build is fully reproducible, not just documented in photos.

### Engineering Notes
* **Added `/CAD`:** Committed the native Fusion 360 archive (`P64-CASE.f3z`), the sliceable top/bottom STL exports, and the print-ready `.3mf` project file used for the final top-shell print.
* **Why this matters:** The shipping guide flags "photos but no design source" submissions for rejection. The STL/F3Z files let a reviewer (or anyone else) re-slice and reprint the exact enclosure without needing to reverse-engineer it from images.
* **Still open before final submission:** an itemized BOM file and demo video link should still be added to the README per the guide's checklist.

## Hour 22: Parametric Power Button Keycap (OpenSCAD)

* **Date:** June 30, 2026

### Activity Summary
The off-the-shelf Cherry MX keycaps sourced earlier were too large for the power-button cutout designed back in Hour 14, so a correctly-sized replacement was generated parametrically in OpenSCAD instead of modeling one from scratch in Fusion 360.

### Engineering Notes
* **Tooling:** Used [KeyV2](https://github.com/rsheldiii/keyv2#how-to-run), an open-source parametric keycap library for OpenSCAD, as the base geometry generator rather than hand-modeling a cap.
* **Why KeyV2 over Fusion:** The library exposes cap width/height, total depth, and stem geometry as simple variables. Shrinking a keycap to fit an undersized cutout is a dimension change, not a modeling problem. KeyV2 turned what would have been a from-scratch CAD job into about an hour of editing config values.
* **Custom Dimensions:** Set `$bottom_key_width`/`$bottom_key_height` to 16mm (down from a standard 1u/19.05mm cap) and `$total_depth` to 7mm to match the Hour 14 side-panel cutout, keeping `$stem_type = "cherry"` so it still seats on the Cherry MX DIO switch soldered in Hour 18.
* **Engraving:** Added a power-button glyph to the cap face directly in the model, avoiding a separate silkscreen, sticker, or paint step to mark the button.
* **Slicing & Print:** Sliced the exported STL and confirmed the engraved icon and 16mm footprint render correctly before printing.
* **Design Source Added:** Committed the finalized export, [`CAD/power-button-keycap-v3.stl`](./CAD/power-button-keycap-v3.stl), so the keycap is reproducible alongside the case CAD from Hour 21.

<div align="center">
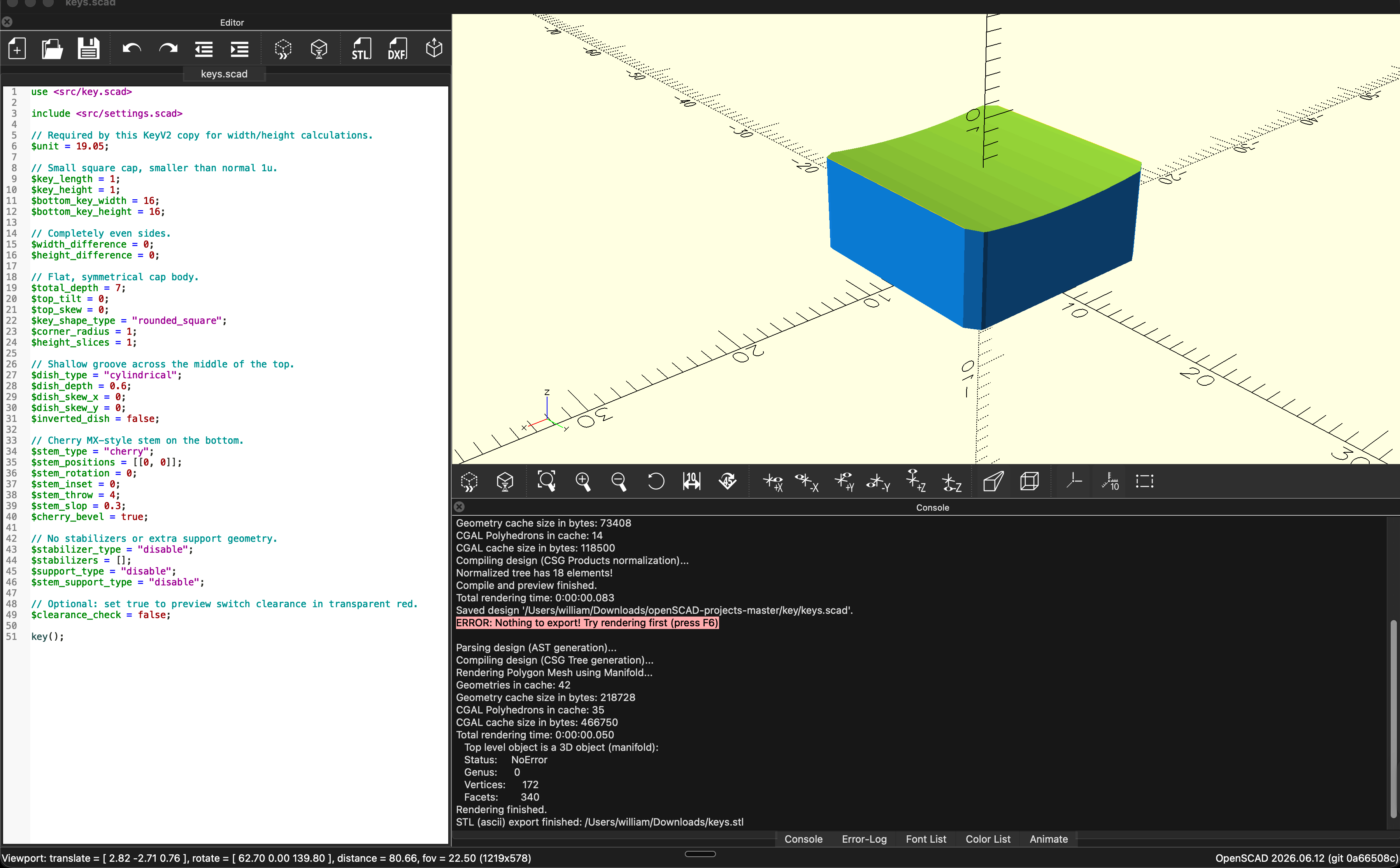
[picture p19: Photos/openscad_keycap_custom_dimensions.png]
OpenSCAD editor showing the KeyV2-based keys.scad script with custom width, height, and depth variables for the undersized cutout
  
</div>

<div align="center">
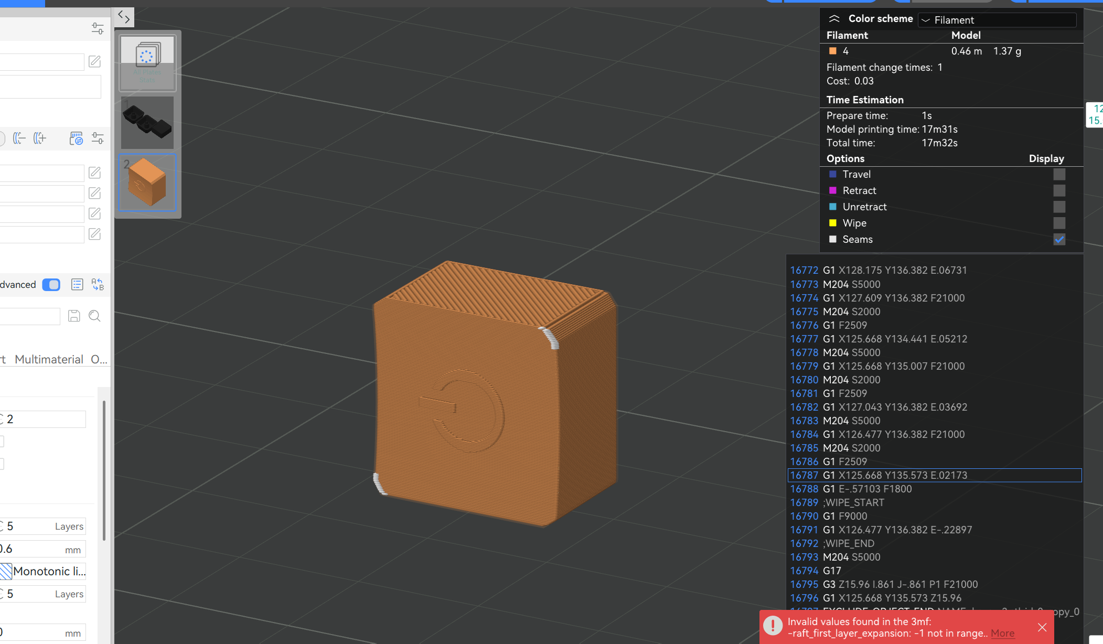
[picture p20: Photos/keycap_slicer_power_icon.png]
Slicer preview of the printed keycap showing the engraved power button icon on the cap face
  
</div>

## Hour 23: Ship-Ready Wiring Schematic & Electrical Safety Review

* **Date:** June 30, 2026

### Activity Summary
Consolidated every wiring decision from Hours 2, 17, and 18 into a single, verified electrical schematic before final submission: one reference diagram covering board power, fan power, and the power button, with a pre-power checklist to run before energizing a fresh build.

### The Golden Rule
**5 V powers the Pine A64. 12 V powers only the Noctua fan. 12 V never touches the Pine A64 GPIO/header pins.**

### Engineering Notes

**1. Main board power**: The Pine A64 runs from a regulated 5 V supply (2 A or more recommended), either through microUSB or internally via the Euler header's DC-in pins:
```text
5 V regulated PSU + → PINE A64 microUSB power input
5 V regulated PSU - → PINE A64 ground

# Internal alternative:
5 V regulated PSU + → Euler pin 2 or pin 4, DC IN
5 V regulated PSU - → Euler pin 6 or pin 9, GND
```

**2. Fan power system**: The 5 V rail is split so the MT3608 draws directly from the PSU rather than through the board, keeping the fan's startup current off the Pine A64 entirely:
```text
5 V PSU
  ├── PINE A64 power input
  └── MT3608 boost converter input (IN+ / IN-)
```
The internal-header variant (`PINE A64 5V pin → MT3608 IN+`, `PINE A64 GND pin → MT3608 IN-`) used in Hour 17 is acceptable as long as the supply has current headroom and the wire run is short.

**3. MT3608 output adjustment**: Before the fan is ever connected, the output is measured and tuned:
```text
Multimeter red probe   → MT3608 OUT+
Multimeter black probe → MT3608 OUT-
Adjust potentiometer   → 12.0 V DC
```

**4. Noctua fan wiring:**
```text
MT3608 OUT+ → Noctua red wire   (+12 V)
MT3608 OUT- → Noctua black wire (Ground)
Noctua yellow wire → not connected, insulated (tachometer / RPM, unused)
```
The yellow wire is never connected to 5 V, 12 V, or ground; it is just insulated and left disconnected, matching the original wiring decision from the project overview.

**5. Key switch as power button**: Wired to the EXP header, acting as a momentary normally-open signal rather than a hard power cut:
```text
Key switch terminal 1 → EXP pin 5, Pwr/Stb Sw
Key switch terminal 2 → EXP pin 6, GND
```
Wiring the switch in series with the main 5 V line was deliberately avoided because cutting power directly while DietPi is running risks corrupting the microSD card. Signaling the standby pin instead lets the board shut down cleanly.

**6. Display, network, USB, and audio**: All standard external ports:
```text
HDMI port     → Monitor or display
Ethernet RJ45 → Router/network switch (preferred over Wi-Fi for Moonlight for lower latency and better stability)
USB ports     → Keyboard, mouse, controller, or USB dongle
microSD slot  → DietPi / Linux boot card
3.5 mm audio  → Optional speakers or headphones
```

### Pre-Power Checklist
Run through this before applying power for the first time on a fresh build:
1. Verify the power supply outputs about 5.0 V DC.
2. Verify MT3608 input polarity: IN+ is 5 V, IN- is ground.
3. Verify MT3608 output is adjusted to 12.0 V before connecting the fan.
4. Verify fan red goes to MT3608 OUT+.
5. Verify fan black goes to MT3608 OUT-.
6. Verify the fan yellow wire is insulated and not connected.
7. Verify the key switch connects EXP pin 5 to EXP pin 6 only when activated.
8. Verify no 12 V wire from the MT3608 touches the Pine A64.
9. Power on the board.
10. Confirm the fan spins.
11. Confirm fan airflow direction using the arrows molded into the fan frame.

### Final Electrical Rule
```text
5 V → PINE A64 and MT3608 input
12 V → Noctua fan only
Key switch → EXP pin 5 to GND
```

## Hour 24: Finalized CAD Renders, Print Settings & Assembly Instructions

* **Date:** July 1, 2026

### Activity Summary
Rendered the finalized enclosure model from two angles for documentation, and wrote down the exact printer/filament/slicer settings and final assembly sequence so the whole build (not just the electronics) is reproducible from this repo alone.

### Finalized CAD Renders

<div align="center">
  Fusion 360 render of the finished enclosure showing the fan cutout and side port openings
</div>

<div align="center">
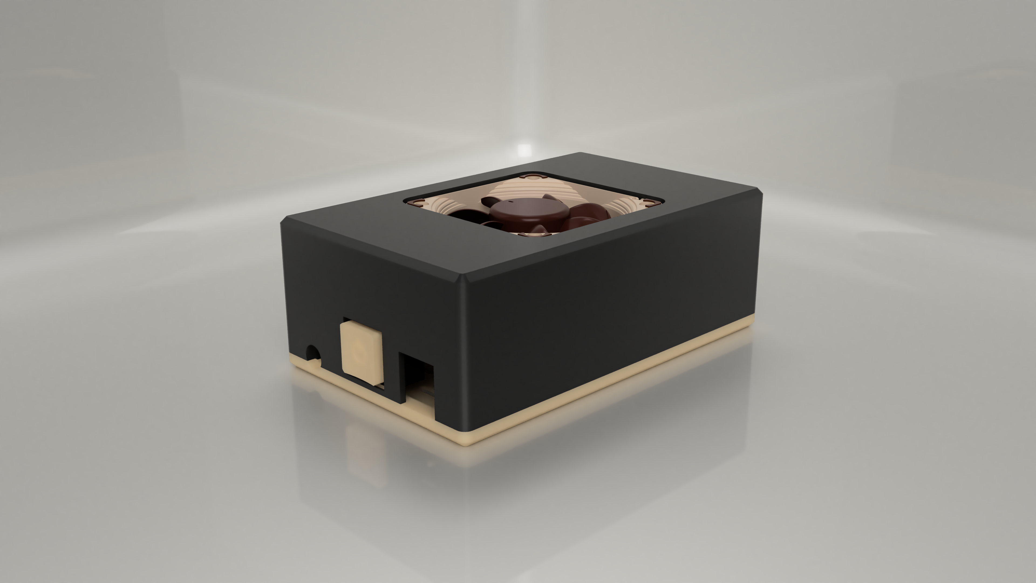
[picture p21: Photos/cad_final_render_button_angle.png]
Fusion 360 render of the finished enclosure showing the fan cutout, power button cutout, and port opening
  
</div>

### 3D Printing Setup

Two different printers were used for the two shells, since each was tuned for a different priority (surface finish on top, strength/print speed on the bottom):

| Part | Printer | Filament | Layer height | Infill | Supports |
|---|---|---|---|---|---|
| Top case | Snapmaker U1 | Bambu PLA Basic (Black), with Bambu Support for PLA | 0.20 mm | 10% gyroid | Normal (snug), using dedicated support material |
| Bottom case | Anycubic Kobra X | JAYO PLA+ (Wood) | 0.16 mm (high quality) | 15% gyroid | None |

The top case needs supports under the fan cutout and pillar overhangs, so it's printed with a dedicated support material for clean removal. The bottom case is mostly flat load-bearing geometry, so it prints support-free at a finer layer height instead.

### Final Assembly Sequence

This is the order that produces a working, fully assembled unit: install heatsinks first, since they're far harder to seat correctly once the fan and wiring are in the way:

1. **Heatsinks first.** Install heatsinks on the CPU, RAM, SD card slot, and any other chip that generates heat, before anything else goes into the case.
2. **Seat the fan.** Rotate the Noctua fan between the two pillars that have screw holes until it drops into place, with the pillar sandwiched between the top and bottom corners of the fan (see Hour 13 and Hour 16 for why only specific pillars work).
3. **Secure the fan.** Screw the fan down with 2 M3 screws. If a mounting point is loose, add a drop of super glue to lock it down.
4. **Wire and manage cables.** Wire and solder the fan, power button, and board connections per Hours 17–18, then do cable management. Hot glue is recommended for strain relief (Hour 20).
5. **Close the case.** Screw in the 4 bottom M3 screws to join the top and bottom shells into one sealed unit.
6. **Done.** Power on and run the verification checklist from Hour 20 / Hour 23.

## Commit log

2026-06-29 feat: add cad process for devlog
2026-07-01 feat: complete devlog, add cad
    [P64-case-bottom.stl, P64-case-top-v1.4.1.3mf, P64-case-top-v1.4.1.stl]
2026-07-01 feat: add ship-ready wiring schematic, firmware config, keycap CAD, and BOM
    - Add Hour 23 devlog entry consolidating the full electrical schematic
    (5V/12V rail separation, MT3608 tuning, fan wiring, EXP header power
    button) with a pre-power safety checklist
    - Correct all power-button pin references from Euler bus pins 27/34 to
    the actual EXP header pins 5/6 across Hours 2, 17, 18, and the README,
    and rename the corresponding photo for consistency
    - Commit firmware-config/ (dietpiEnv.txt, Moonlight autostart script,
    KMS udev rule, install.sh) so the DietPi setup is reviewable and
    reproducible instead of only narrated in the devlog
    - Add the finalized power button keycap STL to /CA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
    [Pine A64 PC Bill of Materials.csv, power-button-keycap-v3.stl]
2026-07-01 feat: ship ready
    [Pine A64 PC Bill of Materials.csv]
2026-07-02 feat: Added CAD renders, polished logs
